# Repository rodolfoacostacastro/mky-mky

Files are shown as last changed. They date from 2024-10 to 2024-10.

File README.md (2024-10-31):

# A mky-mky clone for an RP2040 custom board

parasit

## Arduino Code

updated code after first workshop with minor improvements and better comments :)! 

This the code is situable for a makey makey that works with the chip RP2040.

To upload with the Arduino IDE, you will need to use this board definition(!):

https://github.com/earlephilhower/arduino-pico/releases/download/global/package_rp2040_index.json

go here --> Arduino >settings and scroll down until "Additional boards manager URLs" and paste the link above.

When selecting your board, asure you that it is the Raspberryi Pico/RP definition (and not the native from Arduino)

The code's been modified and works with the educational breakout-board created by Rodolfo Acosta Castro 
for the workshop "Into the Circuit" @ HfS, Berlin. October 2024

Credits:

 //////// MaKey MaKey FIRMWARE v1.4 /////////////
 by: Eric Rosenbaum, Jay Silver, and Jim Lindblom
 MIT Media Lab & Sparkfun
 release: 7/5/2012

## KiCad Files 

you find in this repository the KiCad Project files of the RP2040 Board and the Keyboard extension.
They were created using KiCad 8.0

## Fabrication Files

if you want to order the pcbs yourself you find all the needed files here

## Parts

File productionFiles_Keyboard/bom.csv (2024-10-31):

Designator | Footprint | Quantity | Value | LCSC Part #
Conn1 | mky_mky_boardPads | 1 | ~
GDN_pads1 | mky_mky_complete_GND | 1 | Conn_01x11_Pin
R1, R2, R3, R4, R5, R6, R7 | 0402 | 7 | 10M
TH_externPads1 | mky_mky_externPads | 1 | Conn_01x07_Pin

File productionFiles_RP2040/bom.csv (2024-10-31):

Designator | Footprint | Quantity | Value | LCSC Part #
C1, C2 | 0603 | 2 | 10pf | C1634
C10, C11, C12, C3, C4, C7, C9 | 0603 | 7 | 0.1uF | C14663
C13, C14 | 0805 | 2 | 10uf | C15850
C5, C6, C8 | 0603 | 3 | 1uF | C15849
Conn1 | rp2040_roundStamp_BIG | 1 | customConn
D1 | 0603 | 1 | LED | C189306
D3, D4 | D_SOD-323_HandSoldering | 2 | NSR0320 | C48192
F1 | 0805 | 1 | 500mA, 6V | C269104
J1 | USB_C_Receptacle_TYPE-C-31-M-12 | 1 | USB_C_Receptacle_USB2.0_16P | C165948
LED1 | LED-SMD_4P-L5.0-W5.0-TL_WS2812B-B | 1 | WS2812B-B/W | C2761795
R1, R8 | 0603 | 2 | 10k | C25804
R2, R7, R9 | 0603 | 3 | 1k | C21190
R3, R4 | 0603 | 2 | 5.1K | C23186
R5, R6 | 0603 | 2 | 27 | C100925
SW1, SW2 | SW_B3U-1000P | 2 | SW_Push | C231329
TP1, TP2 | TestPoint_Pad_D2.0mm | 2 | TestPoint
U1 | RP2040-QFN-56 | 1 | RP2040 | C2040
U2 | SON80P400X400X60-9N | 1 | W25Q64JVXGIQ 8MB QSPI Flash | C2940195
U3 | SOT-23-5 | 1 | AP2112K-3.3 | C23380830
X1 | CRYSTAL-SMD_4P-L3.2-W2.5-BL | 1 | ABM8-272-T3_C20625731 | C20625731

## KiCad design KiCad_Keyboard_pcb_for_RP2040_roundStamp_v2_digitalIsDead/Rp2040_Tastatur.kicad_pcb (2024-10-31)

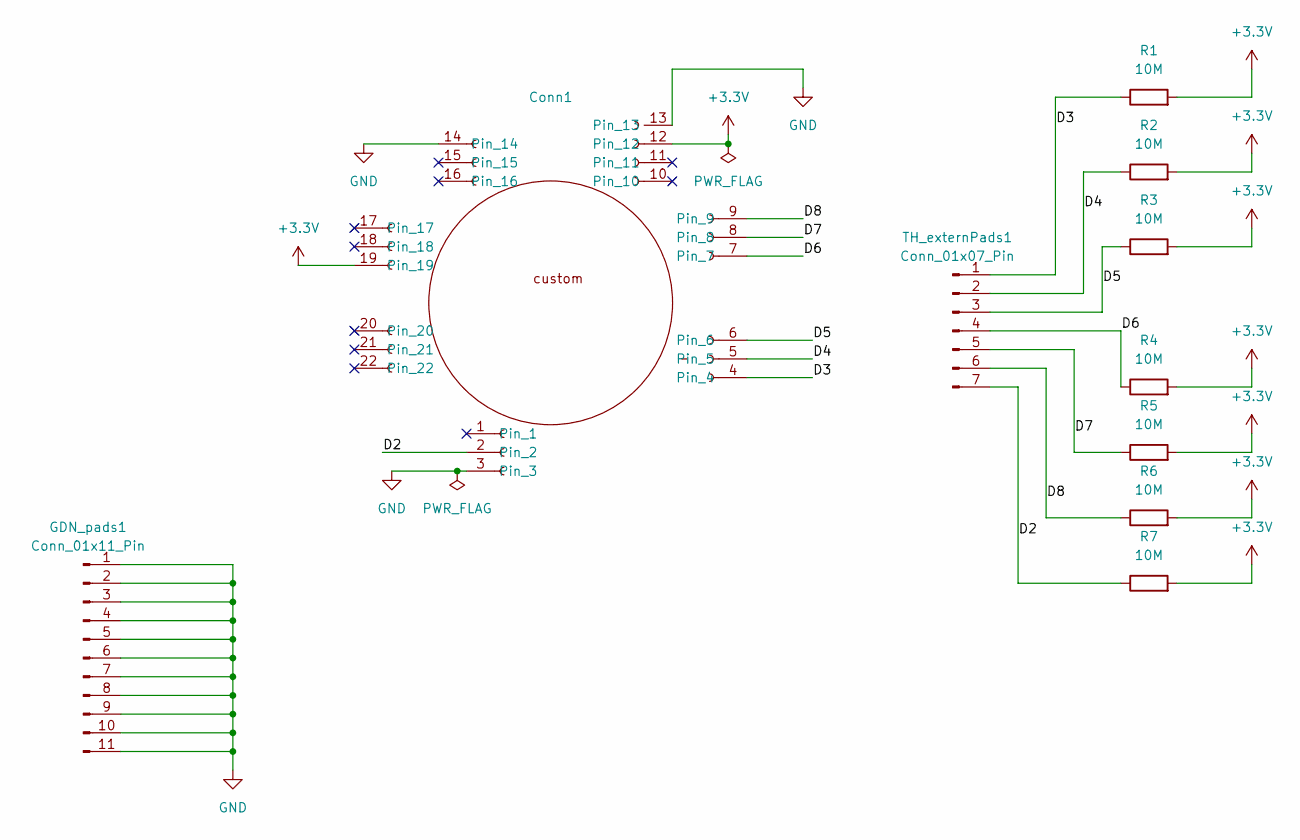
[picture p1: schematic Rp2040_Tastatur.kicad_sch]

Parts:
Conn1: mky_mky_boardPads
GDN_pads1: Conn_01x11_Pin; mky_mky_complete_GND
R1, R2, R3, R4, R5, R6, R7: 10M; R_0402_1005Metric_Pad0.72x0.64mm_HandSolder
TH_externPads1: Conn_01x07_Pin; mky_mky_externPads

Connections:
+3.3V: Conn1.12, Conn1.19, R1.2, R2.2, R3.2, R4.2, R5.2, R6.2, R7.2
/D2: Conn1.2, R7.1, TH_externPads1.7
/D3: Conn1.4, R1.1, TH_externPads1.1
/D4: Conn1.5, R2.1, TH_externPads1.2
/D5: Conn1.6, R3.1, TH_externPads1.3
/D6: Conn1.7, R4.1, TH_externPads1.4
/D7: Conn1.8, R5.1, TH_externPads1.5
/D8: Conn1.9, R6.1, TH_externPads1.6
GND: Conn1.3, Conn1.13, Conn1.14, GDN_pads1.1, GDN_pads1.2, GDN_pads1.3, GDN_pads1.4, GDN_pads1.5, GDN_pads1.6, GDN_pads1.7, GDN_pads1.8, GDN_pads1.9, GDN_pads1.10, GDN_pads1.11

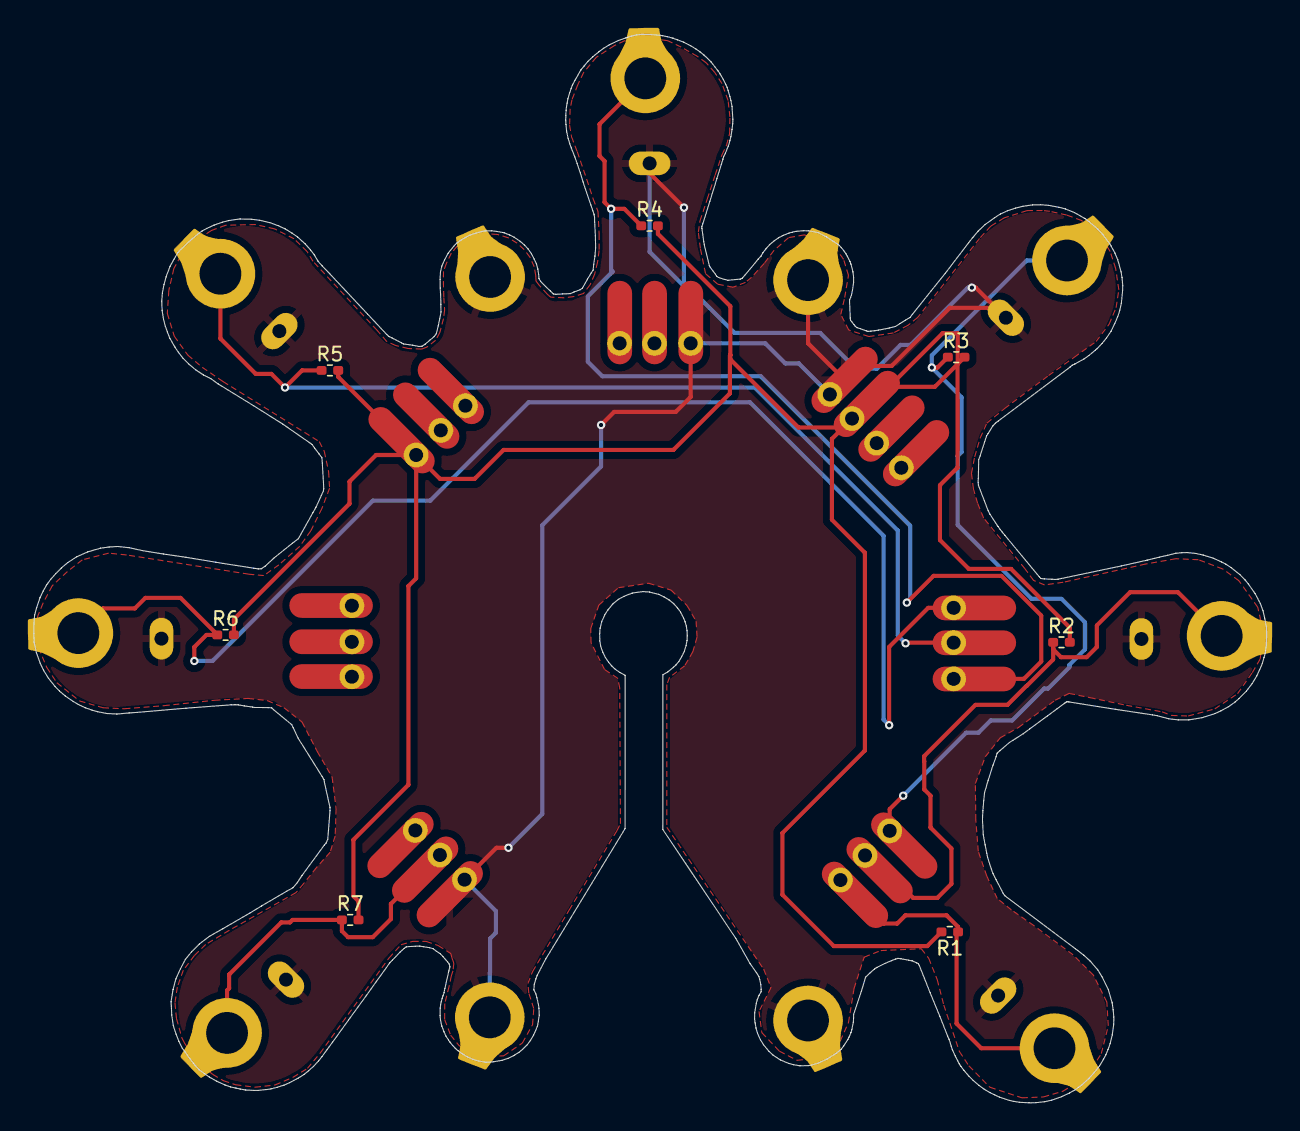
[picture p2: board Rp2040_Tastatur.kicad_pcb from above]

Board: 2 copper layers, 88.5 x 76.7 mm, 10 parts (0 on the bottom side), 9 nets.

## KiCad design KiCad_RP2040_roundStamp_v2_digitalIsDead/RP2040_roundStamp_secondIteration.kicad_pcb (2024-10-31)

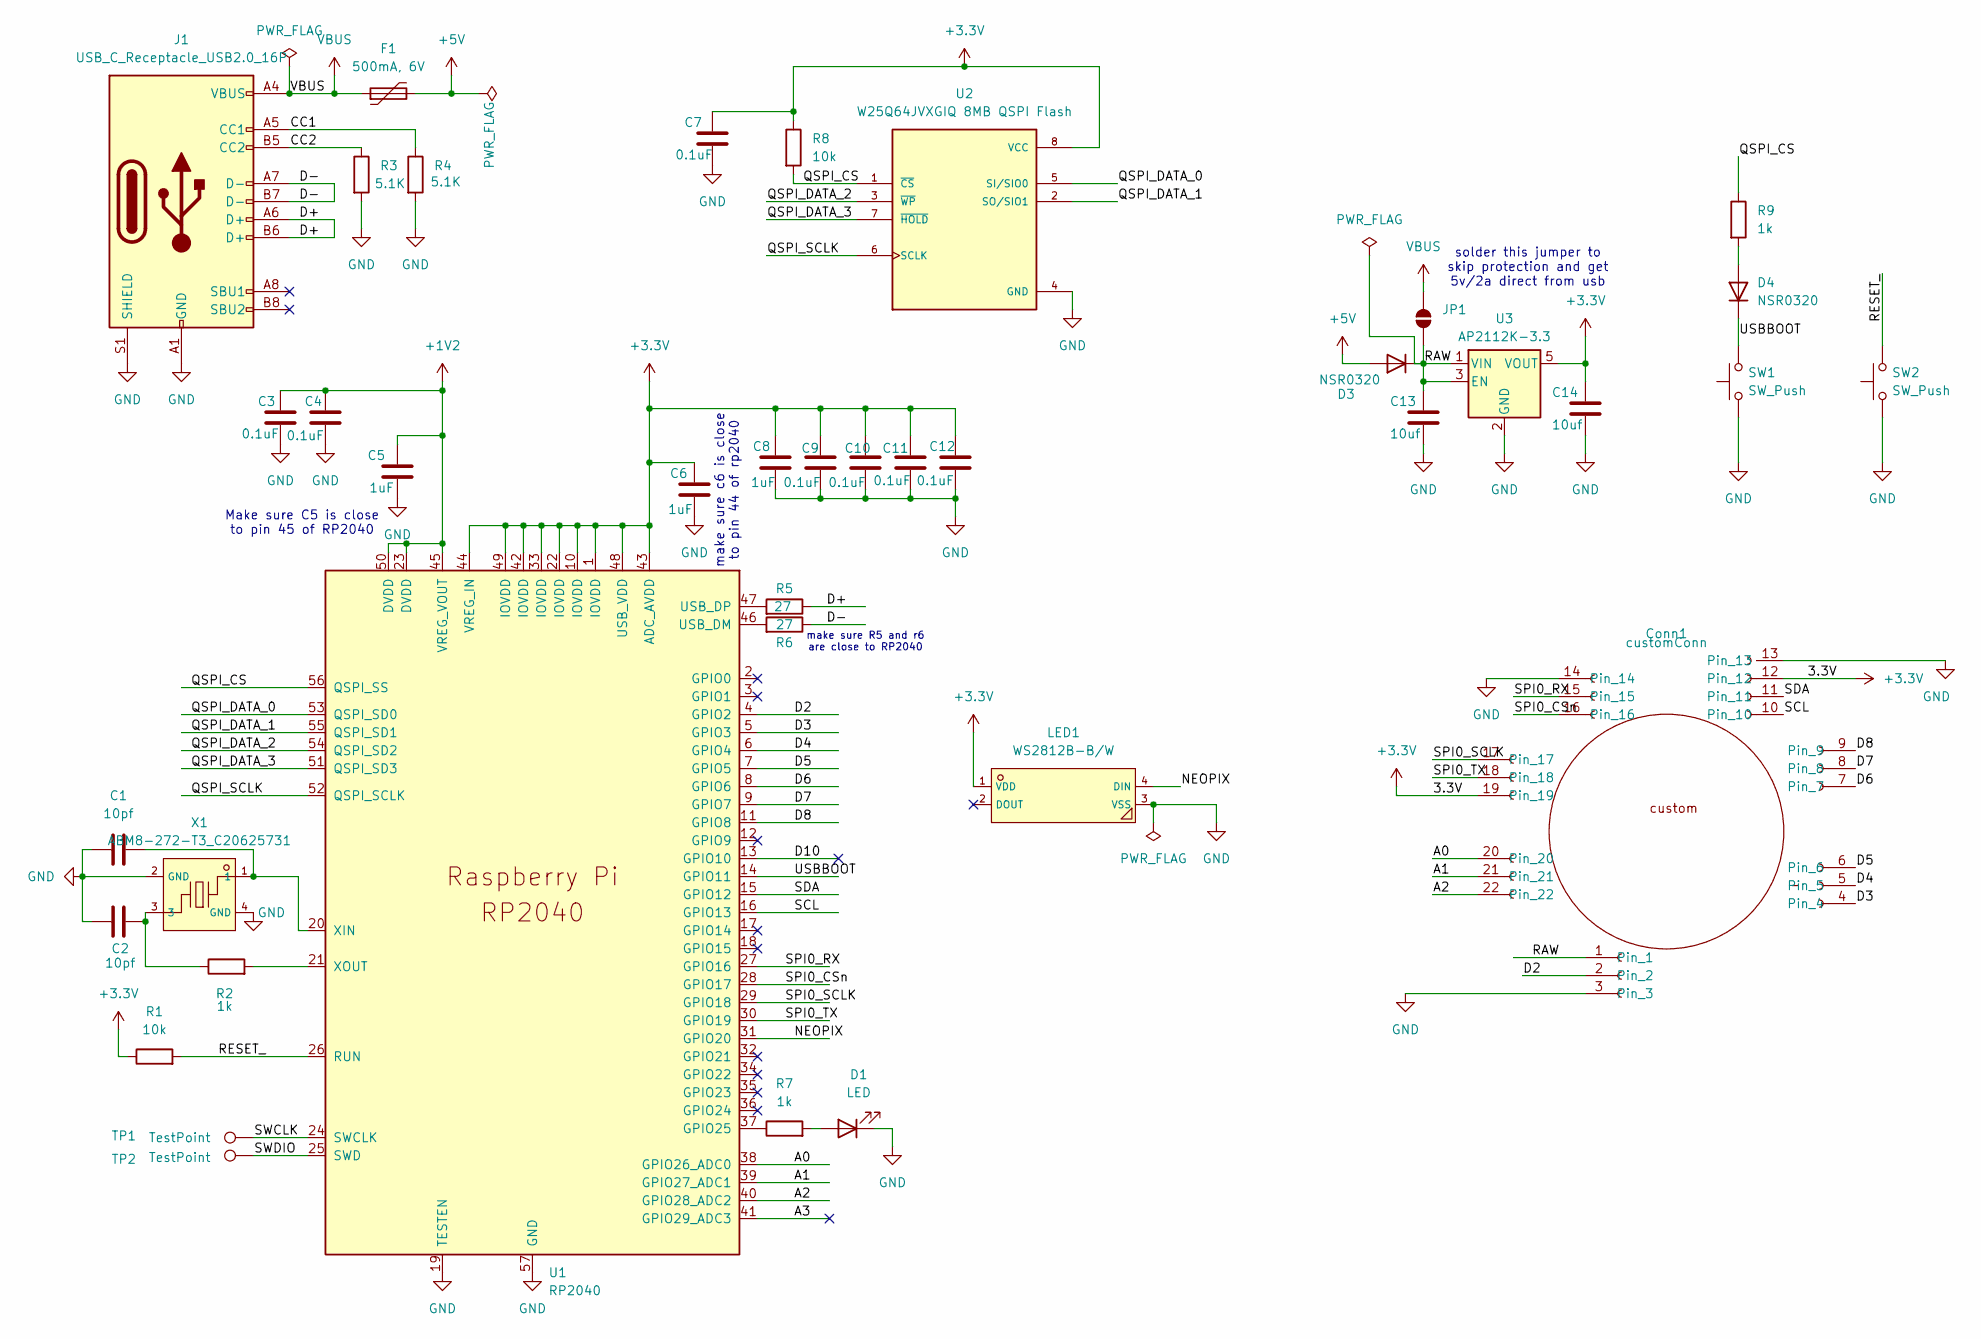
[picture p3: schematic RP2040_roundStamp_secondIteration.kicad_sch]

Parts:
C1, C2: 10pf; C_0603_1608Metric_Pad1.08x0.95mm_HandSolder; LCSC Part C1634
C3, C4, C7, C9, C10, C11, C12: 0.1uF; C_0603_1608Metric_Pad1.08x0.95mm_HandSolder; LCSC Part C14663
C5, C6, C8: 1uF; C_0603_1608Metric_Pad1.08x0.95mm_HandSolder; LCSC Part C15849
C13, C14: 10uf; C_0805_2012Metric_Pad1.18x1.45mm_HandSolder; LCSC Part C15850
Conn1: customConn; rp2040_roundStamp_BIG
D1: LED; LED_0603_1608Metric; LCSC Part C189306
D3, D4: NSR0320; D_SOD-323_HandSoldering; LCSC Part C48192
F1: 500mA, 6V; Fuse_0805_2012Metric; LCSC Part C269104
J1: USB_C_Receptacle_USB2.0_16P; USB_C_Receptacle_TYPE-C-31-M-12; LCSC Part C165948
JP1: SolderJumper_2_Open; SolderJumper-2_P1.3mm_Open_TrianglePad1.0x1.5mm
LED1: WS2812B-B/W; LED-SMD_4P-L5.0-W5.0-TL_WS2812B-B; LCSC C2761795
R1, R8: 10k; R_0603_1608Metric_Pad0.98x0.95mm_HandSolder; LCSC Part C25804
R2, R7, R9: 1k; R_0603_1608Metric_Pad0.98x0.95mm_HandSolder; LCSC Part C21190
R3, R4: 5.1K; R_0603_1608Metric_Pad0.98x0.95mm_HandSolder; LCSC Part C23186
R5, R6: 27; R_0603_1608Metric_Pad0.98x0.95mm_HandSolder; LCSC Part C100925
SW1, SW2: SW_Push; SW_B3U-1000P; LCSC Part C231329
TP1, TP2: TestPoint; TestPoint_Pad_D2.0mm
U1: RP2040; RP2040-QFN-56; LCSC Part C2040
U2: W25Q64JVXGIQ 8MB QSPI Flash; SON80P400X400X60-9N; LCSC Part C2940195
U3: AP2112K-3.3; SOT-23-5; LCSC Part C23380830
X1: ABM8-272-T3_C20625731; CRYSTAL-SMD_4P-L3.2-W2.5-BL; LCSC C20625731

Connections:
+1V2: C3.1, C4.1, C5.1, U1.23 (DVDD), U1.45 (VREG_VOUT), U1.50 (DVDD)
+3.3V: C6.1, C7.1, C8.1, C9.1, C10.1, C11.1, C12.1, C14.1, Conn1.12, Conn1.19, LED1.1 (VDD), R1.1, R8.1, U1.1 (IOVDD), U1.10 (IOVDD), U1.22 (IOVDD), U1.33 (IOVDD), U1.42 (IOVDD), U1.43 (ADC_AVDD), U1.44 (VREG_IN), U1.48 (USB_VDD), U1.49 (IOVDD), U2.8 (VCC), U3.5 (VOUT)
+5V: D3.2 (A), F1.2
/A0: Conn1.20, U1.38 (GPIO26_ADC0)
/A1: Conn1.21, U1.39 (GPIO27_ADC1)
/A2: Conn1.22, U1.40 (GPIO28_ADC2)
/A3: U1.41 (GPIO29_ADC3)
/CC1: J1.A5 (CC1), R4.1
/CC2: J1.B5 (CC2), R3.1
/D2: Conn1.2, U1.4 (GPIO2)
/D3: Conn1.4, U1.5 (GPIO3)
/D4: Conn1.5, U1.6 (GPIO4)
/D5: Conn1.6, U1.7 (GPIO5)
/D6: Conn1.7, U1.8 (GPIO6)
/D7: Conn1.8, U1.9 (GPIO7)
/D8: Conn1.9, U1.11 (GPIO8)
/D10: U1.13 (GPIO10)
/D+: J1.A6 (D+), J1.B6 (D+), R5.1
/D-: J1.A7 (D-), J1.B7 (D-), R6.1
/NEOPIX: LED1.4 (DIN), U1.31 (GPIO20)
/QSPI_CS: R8.2, R9.1, U1.56 (QSPI_SS), U2.1 (~CS)
/QSPI_DATA_0: U1.53 (QSPI_SD0), U2.5 (SI/SIO0)
/QSPI_DATA_1: U1.55 (QSPI_SD1), U2.2 (SO/SIO1)
/QSPI_DATA_2: U1.54 (QSPI_SD2), U2.3 (~WP)
/QSPI_DATA_3: U1.51 (QSPI_SD3), U2.7 (~HOLD)
/QSPI_SCLK: U1.52 (QSPI_SCLK), U2.6 (SCLK)
/RAW: C13.1, Conn1.1, D3.1 (K), JP1.1 (A), U3.1 (VIN), U3.3 (EN)
/RESET_: R1.2, SW2.2, U1.26 (RUN)
/SCL: Conn1.10, U1.16 (GPIO13)
/SDA: Conn1.11, U1.15 (GPIO12)
/SPI0_CSn: Conn1.16, U1.28 (GPIO17)
/SPI0_RX: Conn1.15, U1.27 (GPIO16)
/SPI0_SCLK: Conn1.17, U1.29 (GPIO18)
/SPI0_TX: Conn1.18, U1.30 (GPIO19)
/SWCLK: TP1.1, U1.24 (SWCLK)
/SWDIO: TP2.1, U1.25 (SWD)
/USBBOOT: D4.1 (K), SW1.2, U1.14 (GPIO11)
GND: C1.1, C2.1, C3.2, C4.2, C5.2, C6.2, C7.2, C8.2, C9.2, C10.2, C11.2, C12.2, C13.2, C14.2, Conn1.3, Conn1.13, Conn1.14, D1.1 (K), J1.A1 (GND), J1.A12 (GND), J1.B1 (GND), J1.B12 (GND), J1.S1 (SHIELD), LED1.3 (VSS), R3.2, R4.2, SW1.1, SW2.1, U1.19 (TESTEN), U1.57 (GND), U2.4 (GND), U3.2 (GND), X1.2 (GND), X1.4 (GND)
unnamed: C2.2, R2.1, X1.3
unnamed: D1.2 (A), R7.2
unnamed: D4.2 (A), R9.2
unnamed: R7.1, U1.37 (GPIO25)
unnamed: R6.2, U1.46 (USB_DM)
unnamed: R5.2, U1.47 (USB_DP)
unnamed: C1.2, U1.20 (XIN), X1.1
unnamed: R2.2, U1.21 (XOUT)
VBUS: F1.1, J1.A4 (VBUS), J1.A9 (VBUS), J1.B4 (VBUS), J1.B9 (VBUS), JP1.2

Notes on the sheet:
make sure R5 and r6 are close to RP2040
make sure c6 is close to pin 44 of rp2040
Make sure C5 is close to pin 45 of RP2040
solder this jumper to skip protection and get 5v/2a direct from usb

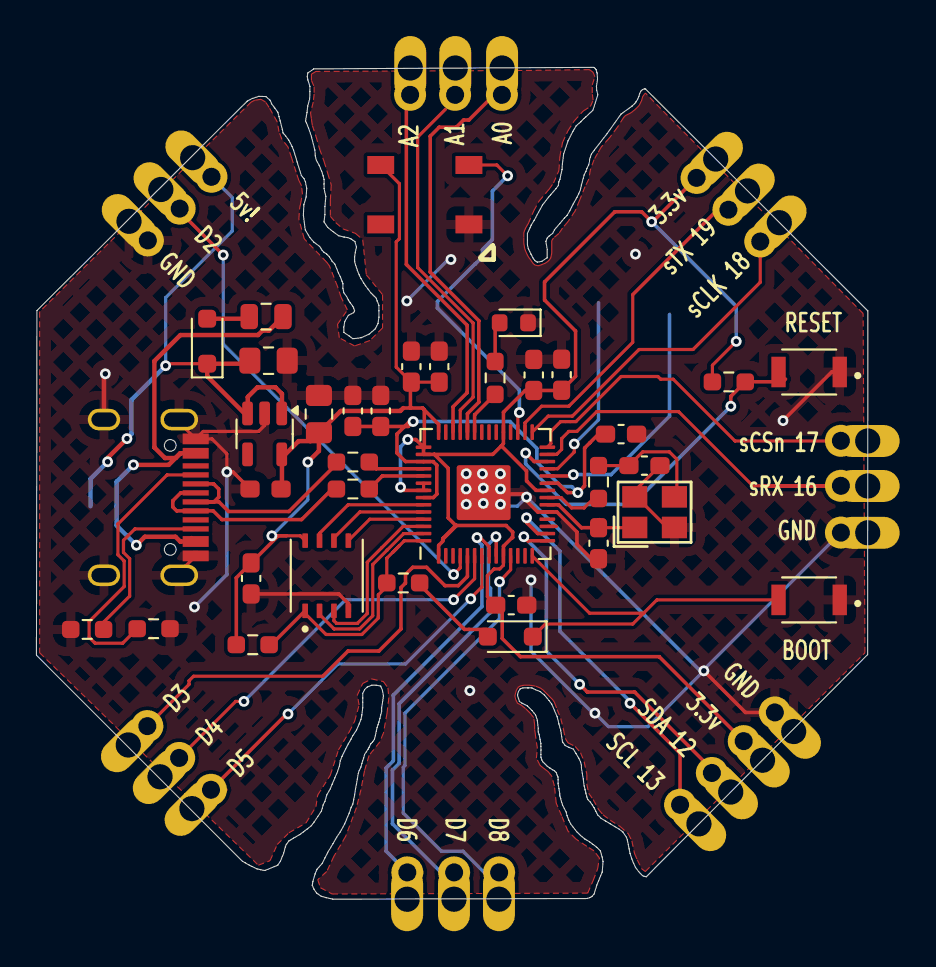
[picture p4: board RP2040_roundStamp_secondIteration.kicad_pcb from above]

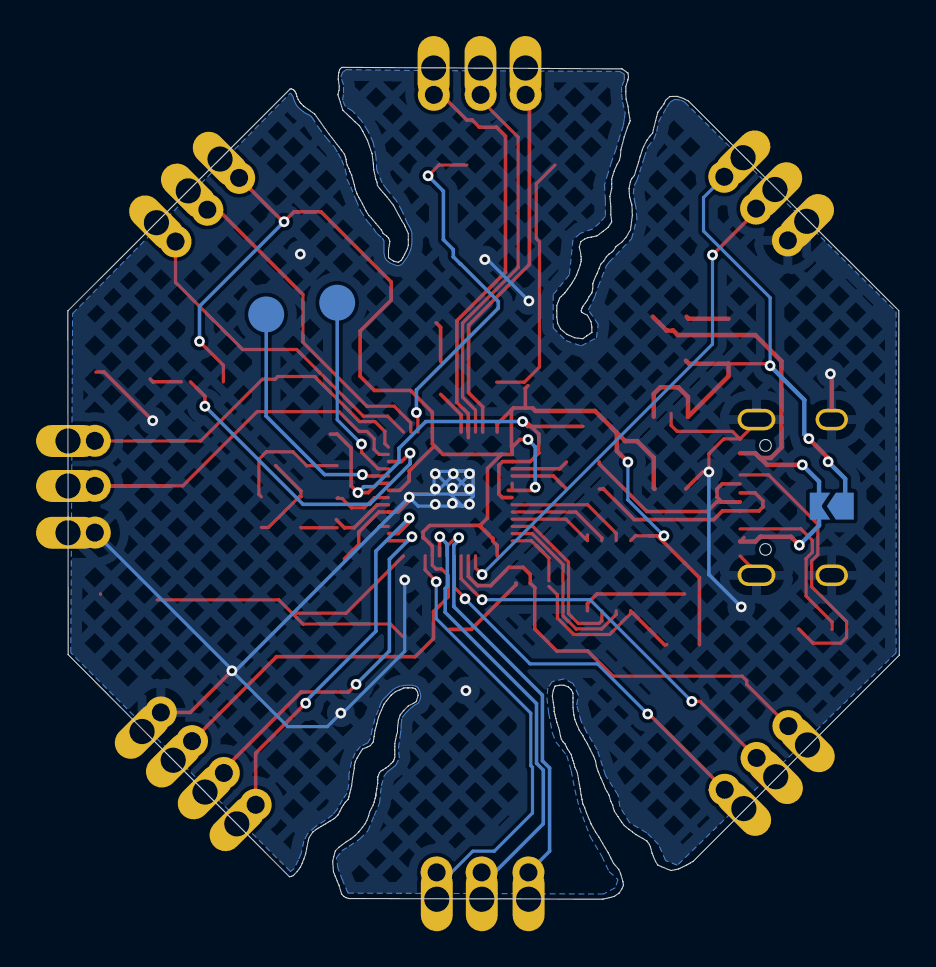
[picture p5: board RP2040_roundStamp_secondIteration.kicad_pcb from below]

Board: 2 copper layers, 46.2 x 46.2 mm, 39 parts (3 on the bottom side), 45 nets.

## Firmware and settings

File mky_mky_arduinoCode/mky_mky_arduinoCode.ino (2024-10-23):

/*

This is the code for the makey makey clone, that works with the chip RP2040.
You need to use this core to use it as a keyboard:
https://github.com/earlephilhower/arduino-pico/releases/download/global/package_rp2040_index.json

The code's been modified and works with the educational breakout-board created by Rodolfo Acosta Castro 
for the workshop "Into the Circuit" @ HfS, Berlin. October 2024

Credits:
 ************** MAKEY MAKEY *********************
 /////////////HOW TO EDIT THE KEYS //////// /////////////////////////////////////////////////
///////
 - Edit keys in the settings.h file
 - that file should be open in a tab above (in Arduino IDE)
 - more instructions are in that file
 
 //////// MaKey MaKey FIRMWARE v1.4 /////////////
 by: Eric Rosenbaum, Jay Silver, and Jim Lindblom
 MIT Media Lab & Sparkfun
 release: 7/5/2012
 */

////////////////////////
// DEFINED CONSTANTS////
////////////////////////

#define BUFFER_LENGTH    3     // 3 bytes gives us 24 samples
#define NUM_INPUTS       7   // 6 on the front + 12 on the back
//#define TARGET_LOOP_TIME 694   // (1/60 seconds) / 24 samples = 694 microseconds per sample 
//#define TARGET_LOOP_TIME 758  // (1/55 seconds) / 24 samples = 758 microseconds per sample 
#define TARGET_LOOP_TIME 744  // (1/56 seconds) / 24 samples = 744 microseconds per sample 

// id numbers for mouse movement inputs (used in settings.h)
#define MOUSE_MOVE_UP       -1 
#define MOUSE_MOVE_DOWN     -2
#define MOUSE_MOVE_LEFT     -3
#define MOUSE_MOVE_RIGHT    -4

#include <Keyboard.h>
#include <Mouse.h>
#include "settings.h"

/////////////////////////
// STRUCT ///////////////
/////////////////////////
typedef struct {
  byte pinNumber;
  int keyCode;
  byte measurementBuffer[BUFFER_LENGTH]; 
  boolean oldestMeasurement;
  byte bufferSum;
  boolean pressed;
  boolean prevPressed;
  boolean isMouseMotion;
  boolean isMouseButton;
  boolean isKey;
} 
MakeyMakeyInput;

MakeyMakeyInput inputs[NUM_INPUTS];

///////////////////////////////////
// VARIABLES //////////////////////
///////////////////////////////////
int bufferIndex = 0;
byte byteCounter = 0;
byte bitCounter = 0;
int mouseMovementCounter = 0; // for sending mouse movement events at a slower interval

int pressThreshold;
int releaseThreshold;
boolean inputChanged;

int mouseHoldCount[NUM_INPUTS]; // used to store mouse movement hold data

// Pin Numbers
int pinNumbers[NUM_INPUTS] = {
 2, 3, 4, 5, 6, 7, 8  // top of board
};

// input status LED pin numbers
const int inputLED_a = 25;
byte ledCycleCounter = 0;

 // timing
int loopTime = 0;
int prevTime = 0;
int loopCounter = 0;       

///////////////////////////
// FUNCTIONS //////////////
///////////////////////////
void initializeArduino();
void initializeInputs();
void updateMeasurementBuffers();
void updateBufferSums();
void updateBufferIndex();
void updateInputStates();
void sendMouseButtonEvents();
void sendMouseMovementEvents();
void addDelay();
void cycleLEDs();
//void danceLeds();

//////////////////////
// SETUP /////////////
//////////////////////
void setup() 
{
  initializeArduino();
  initializeInputs();
  danceLeds();
}

////////////////////
// MAIN LOOP ///////
////////////////////
void loop() 
{
  updateMeasurementBuffers();
  updateBufferSums();
  updateBufferIndex();
  updateInputStates();
  sendMouseButtonEvents();
  sendMouseMovementEvents();
  cycleLEDs();
  addDelay();
}

//////////////////////////
// INITIALIZE ARDUINO
//////////////////////////
void initializeArduino() {
#ifdef DEBUG
  Serial.begin(9600);  // Serial for debugging
#endif

  /* Set up input pins 
   DEactivate the internal pull-ups, since we're using external resistors */
  for (int i=0; i<NUM_INPUTS; i++)
  {
    pinMode(pinNumbers[i], INPUT);
    digitalWrite(pinNumbers[i], LOW);
  }

  pinMode(inputLED_a, OUTPUT);
  digitalWrite(inputLED_a, LOW);

#ifdef DEBUG
  delay(4000); // allow us time to reprogram in case things are freaking out
#endif

  Keyboard.begin();
  Mouse.begin();
}

///////////////////////////
// INITIALIZE INPUTS
///////////////////////////
void initializeInputs() {

  float thresholdPerc = SWITCH_THRESHOLD_OFFSET_PERC;
  float thresholdCenterBias = SWITCH_THRESHOLD_CENTER_BIAS/50.0;
  float pressThresholdAmount = (BUFFER_LENGTH * 8) * (thresholdPerc / 100.0);
  float thresholdCenter = ( (BUFFER_LENGTH * 8) / 2.0 ) * (thresholdCenterBias);
  pressThreshold = int(thresholdCenter + pressThresholdAmount);
  releaseThreshold = int(thresholdCenter - pressThresholdAmount);

#ifdef DEBUG
  Serial.println(pressThreshold);
  Serial.println(releaseThreshold);
#endif

  for (int i=0; i<NUM_INPUTS; i++) {
    inputs[i].pinNumber = pinNumbers[i];
    inputs[i].keyCode = keyCodes[i];

    for (int j=0; j<BUFFER_LENGTH; j++) {
      inputs[i].measurementBuffer[j] = 0;
    }
    inputs[i].oldestMeasurement = 0;
    inputs[i].bufferSum = 0;

    inputs[i].pressed = false;
    inputs[i].prevPressed = false;

    inputs[i].isMouseMotion = false;
    inputs[i].isMouseButton = false;
    inputs[i].isKey = false;

    if (inputs[i].keyCode < 0) {
#ifdef DEBUG_MOUSE
      Serial.println("GOT IT");  
#endif

      inputs[i].isMouseMotion = true;
    } 
    else if ((inputs[i].keyCode == MOUSE_LEFT) || (inputs[i].keyCode == MOUSE_RIGHT)) {
      inputs[i].isMouseButton = true;
    } 
    else {
      inputs[i].isKey = true;
    }
#ifdef DEBUG
    Serial.println(i);
#endif

  }
}


//////////////////////////////
// UPDATE MEASUREMENT BUFFERS
//////////////////////////////
void updateMeasurementBuffers() {

  for (int i=0; i<NUM_INPUTS; i++) {

    // store the oldest measurement, which is the one at the current index,
    // before we update it to the new one 
    // we use oldest measurement in updateBufferSums
    byte currentByte = inputs[i].measurementBuffer[byteCounter];
    inputs[i].oldestMeasurement = (currentByte >> bitCounter) & 0x01; 

    // make the new measurement
    boolean newMeasurement = digitalRead(inputs[i].pinNumber);

    // invert so that true means the switch is closed
    newMeasurement = !newMeasurement; 

    // store it    
    if (newMeasurement) {
      currentByte |= (1<<bitCounter);
    } 
    else {
      currentByte &= ~(1<<bitCounter);
    }
    inputs[i].measurementBuffer[byteCounter] = currentByte;
  }
}

///////////////////////////
// UPDATE BUFFER SUMS
///////////////////////////
void updateBufferSums() {

  // the bufferSum is a running tally of the entire measurementBuffer
  // add the new measurement and subtract the old one

  for (int i=0; i<NUM_INPUTS; i++) {
    byte currentByte = inputs[i].measurementBuffer[byteCounter];
    boolean currentMeasurement = (currentByte >> bitCounter) & 0x01; 
    if (currentMeasurement) {
      inputs[i].bufferSum++;
    }
    if (inputs[i].oldestMeasurement) {
      inputs[i].bufferSum--;
    }
  }  
}

///////////////////////////
// UPDATE BUFFER INDEX
///////////////////////////
void updateBufferIndex() {
  bitCounter++;
  if (bitCounter == 8) {
    bitCounter = 0;
    byteCounter++;
    if (byteCounter == BUFFER_LENGTH) {
      byteCounter = 0;
    }
  }
}

///////////////////////////
// UPDATE INPUT STATES
///////////////////////////
void updateInputStates() {
  inputChanged = false;
  for (int i=0; i<NUM_INPUTS; i++) {
    inputs[i].prevPressed = inputs[i].pressed; // store previous pressed state (only used for mouse buttons)
    if (inputs[i].pressed) {
      if (inputs[i].bufferSum < releaseThreshold) {  
        inputChanged = true;
        inputs[i].pressed = false;
        if (inputs[i].isKey) {
          Keyboard.release(inputs[i].keyCode);
        }
        if (inputs[i].isMouseMotion) {  
          mouseHoldCount[i] = 0;  // input becomes released, reset mouse hold
        }
      }
      else if (inputs[i].isMouseMotion) {  
        mouseHoldCount[i]++; // input remains pressed, increment mouse hold
      }
    } 
    else if (!inputs[i].pressed) {
      if (inputs[i].bufferSum > pressThreshold) {  // input becomes pressed
        inputChanged = true;
        inputs[i].pressed = true; 
        if (inputs[i].isKey) {
          Keyboard.press(inputs[i].keyCode);
        }
      }
    }
  }
#ifdef DEBUG3
  if (inputChanged) {
    Serial.println("change");
  }
#endif
}

/////////////////////////////
// SEND MOUSE BUTTON EVENTS 
/////////////////////////////
void sendMouseButtonEvents() {
  if (inputChanged) {
    for (int i=0; i<NUM_INPUTS; i++) {
      if (inputs[i].isMouseButton) {
        if (inputs[i].pressed) {
          if (inputs[i].keyCode == MOUSE_LEFT) {
            Mouse.press(MOUSE_LEFT);
          } 
          if (inputs[i].keyCode == MOUSE_RIGHT) {
            Mouse.press(MOUSE_RIGHT);
          } 
        } 
        else if (inputs[i].prevPressed) {
          if (inputs[i].keyCode == MOUSE_LEFT) {
            Mouse.release(MOUSE_LEFT);
          } 
          if (inputs[i].keyCode == MOUSE_RIGHT) {
            Mouse.release(MOUSE_RIGHT);
          }           
        }
      }
    }
  }
}

//////////////////////////////
// SEND MOUSE MOVEMENT EVENTS
//////////////////////////////
void sendMouseMovementEvents() {
  byte right = 0;
  byte left = 0;
  byte down = 0;
  byte up = 0;
  byte horizmotion = 0;
  byte vertmotion = 0;

  mouseMovementCounter++;
  mouseMovementCounter %= MOUSE_MOTION_UPDATE_INTERVAL;
  if (mouseMovementCounter == 0) {
    for (int i=0; i<NUM_INPUTS; i++) {
#ifdef DEBUG_MOUSE
      //  Serial.println(inputs[i].isMouseMotion);  
#endif

      if (inputs[i].isMouseMotion) {
        if (inputs[i].pressed) {
          if (inputs[i].keyCode == MOUSE_MOVE_UP) {
            // JL Changes (x4): now update to 1 + a hold factor, constrained between 1 and mouse max movement speed
            up=constrain(1+mouseHoldCount[i]/MOUSE_RAMP_SCALE, 1, MOUSE_MAX_PIXELS);
          }  
          if (inputs[i].keyCode == MOUSE_MOVE_DOWN) {
            down=constrain(1+mouseHoldCount[i]/MOUSE_RAMP_SCALE, 1, MOUSE_MAX_PIXELS);
          }  
          if (inputs[i].keyCode == MOUSE_MOVE_LEFT) {
            left=constrain(1+mouseHoldCount[i]/MOUSE_RAMP_SCALE, 1, MOUSE_MAX_PIXELS);
          }  
          if (inputs[i].keyCode == MOUSE_MOVE_RIGHT) {
            right=constrain(1+mouseHoldCount[i]/MOUSE_RAMP_SCALE, 1, MOUSE_MAX_PIXELS);
          }  
        }
      }
    }

    // diagonal scrolling and left/right cancellation
    if(left > 0)
    {
      if(right > 0)
      {
        horizmotion = 0; // cancel horizontal motion because left and right are both pushed
      }
      else
      {
        horizmotion = -left; // left yes, right no
      }
    }
    else
    {
      if(right > 0)
      {
        horizmotion = right; // right yes, left no
      }
    }

    if(down > 0)
    {
      if(up > 0)
      {
        vertmotion = 0; // cancel vertical motion because up and down are both pushed
      }
      else
      {
        vertmotion = down; // down yes, up no
      }
    }
    else
    {
      if (up > 0)
      {
        vertmotion = -up; // up yes, down no
      }
    }
    // now move the mouse
    if( !((horizmotion == 0) && (vertmotion==0)) )
    {
      Mouse.move(horizmotion * PIXELS_PER_MOUSE_STEP, vertmotion * PIXELS_PER_MOUSE_STEP);
    }
  }
}

///////////////////////////
// ADD DELAY
///////////////////////////
void addDelay() {

  loopTime = micros() - prevTime;
  if (loopTime < TARGET_LOOP_TIME) {
    int wait = TARGET_LOOP_TIME - loopTime;
    delayMicroseconds(wait);
  }

  prevTime = micros();

#ifdef DEBUG_TIMING
  if (loopCounter == 0) {
    int t = micros()-prevTime;
    Serial.println(t);
  }
  loopCounter++;
  loopCounter %= 999;
#endif

}

///////////////////////////
// CYCLE LEDS
///////////////////////////

void cycleLEDs() {

  pinMode(inputLED_a, INPUT);
  digitalWrite(inputLED_a, LOW);

  ledCycleCounter++;
  ledCycleCounter %= 7;

  if ((ledCycleCounter == 0) && inputs[0].pressed) {
    pinMode(inputLED_a, OUTPUT);
    digitalWrite(inputLED_a, HIGH);
  }
  if ((ledCycleCounter == 1) && inputs[1].pressed) {
    pinMode(inputLED_a, OUTPUT);
    digitalWrite(inputLED_a, HIGH);
  }
  if ((ledCycleCounter == 2) && inputs[2].pressed) {
    pinMode(inputLED_a, OUTPUT);
    digitalWrite(inputLED_a, HIGH);
  }
  if ((ledCycleCounter == 3) && inputs[3].pressed) {
    pinMode(inputLED_a, OUTPUT);
    digitalWrite(inputLED_a, HIGH);
  }
  if ((ledCycleCounter == 4) && inputs[4].pressed) {
    pinMode(inputLED_a, OUTPUT);
    digitalWrite(inputLED_a, HIGH);
 
  }
  if ((ledCycleCounter == 5) && inputs[5].pressed) {
    pinMode(inputLED_a, OUTPUT);
    digitalWrite(inputLED_a, HIGH);
  }
    if ((ledCycleCounter == 5) && inputs[6].pressed) {
    pinMode(inputLED_a, OUTPUT);
    digitalWrite(inputLED_a, HIGH);
  }

}

///////////////////////////
// DANCE LEDS
///////////////////////////
void danceLeds()
{
      digitalWrite(inputLED_a, HIGH);
      delay (250);
      digitalWrite(inputLED_a, LOW);
      delay (250);
      digitalWrite(inputLED_a, HIGH);
      delay (250);
      digitalWrite(inputLED_a, LOW);
      delay (250);
      
      digitalWrite(inputLED_a, HIGH);
      delay (100);
      digitalWrite(inputLED_a, LOW);
      delay (100);
      digitalWrite(inputLED_a, HIGH);
      delay (100);
      digitalWrite(inputLED_a, LOW);
      delay (100);
      
      digitalWrite(inputLED_a, HIGH);
      delay (250);
      digitalWrite(inputLED_a, LOW);
      delay (250);
      digitalWrite(inputLED_a, HIGH);
      delay (250);
      digitalWrite(inputLED_a, LOW);

}

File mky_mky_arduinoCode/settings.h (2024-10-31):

#include "Arduino.h"

/*
/////////////////////////////////////////////////////////////////////////
// KEY MAPPINGS: WHICH KEY MAPS TO WHICH PIN ON THE MAKEY MAKEY BOARD? //
/////////////////////////////////////////////////////////////////////////
  
  - edit the keyCodes array below to change the keys sent by the MaKey MaKey for each input
  - the comments tell you which input sends that key 
  - change the keys by replacing them. for example, you can replace 'w' with any other individual letter,
    number, or symbol on your keyboard
  - you can also use codes for other keys such as modifier and function keys (see the
    the list of additional key codes at the bottom of this file)

*/

int keyCodes[NUM_INPUTS] = {
 
 // KEY_UP_ARROW,      // up arrow pad
 // KEY_DOWN_ARROW,    // down arrow pad
 // KEY_LEFT_ARROW,    // left arrow pad
  //KEY_RIGHT_ARROW,   // right arrow pad
  // ' ',              // space button pad
  //MOUSE_LEFT,        // click button pad


  's',                 //*first leg of the board (clock-wise)
  KEY_DOWN_ARROW,      //*last  leg of the board (clock-wise)
  'd',                 //*sixth  leg of the board (clock-wise) 
  'e',                 //*fifth  leg of the board (clock-wise)
  KEY_UP_ARROW,        //*forth leg of the board (the middle one!)
  'q',                 //*third leg of the board (clock-wise)
  'a'                  //*second leg of the board (clock-wise)
  
 // MOUSE_MOVE_UP,      
 // MOUSE_MOVE_DOWN,    
 // MOUSE_MOVE_LEFT,    
 // MOUSE_MOVE_RIGHT,   
 // MOUSE_LEFT,         
 // MOUSE_RIGHT         
};

///////////////////////////
// NOISE CANCELLATION /////
///////////////////////////
#define SWITCH_THRESHOLD_OFFSET_PERC  5    // number between 1 and 49
                                           // larger value protects better against noise oscillations, but makes it harder to press and release
                                           // recommended values are between 2 and 20
                                           // default value is 5

#define SWITCH_THRESHOLD_CENTER_BIAS 55   // number between 1 and 99
                                          // larger value makes it easier to "release" keys, but harder to "press"
                                          // smaller value makes it easier to "press" keys, but harder to "release"
                                          // recommended values are between 30 and 70
                                          // 50 is "middle" 2.5 volt center
                                          // default value is 55
                                          // 100 = 5V (never use this high)
                                          // 0 = 0 V (never use this low
                                          

/////////////////////////
// MOUSE MOTION /////////
/////////////////////////
#define MOUSE_MOTION_UPDATE_INTERVAL  35   // how many loops to wait between 
                                           // sending mouse motion updates
                                           
#define PIXELS_PER_MOUSE_STEP         4     // a larger number will make the mouse
                                           // move faster

#define MOUSE_RAMP_SCALE              150  // Scaling factor for mouse movement ramping
                                           // Lower = more sensitive mouse movement
                                           // Higher = slower ramping of speed
                                           // 0 = Ramping off
                                            
#define MOUSE_MAX_PIXELS              10   // Max pixels per step for mouse movement

/*

///////////////////////////
// ADDITIONAL KEY CODES ///
///////////////////////////

- you can use these codes in the keyCodes array above
- to get modifier keys, function keys, etc 

KEY_LEFT_CTRL
KEY_LEFT_SHIFT		
KEY_LEFT_ALT		
KEY_LEFT_GUI		
KEY_RIGHT_CTRL		
KEY_RIGHT_SHIFT		
KEY_RIGHT_ALT	
KEY_RIGHT_GUI		

KEY_BACKSPACE		
KEY_TAB				
KEY_RETURN			
KEY_ESC				
KEY_INSERT			
KEY_DELETE			
KEY_PAGE_UP			
KEY_PAGE_DOWN		
KEY_HOME
KEY_END				
KEY_CAPS_LOCK	
	
KEY_F1				
KEY_F2				
KEY_F3				
KEY_F4				
KEY_F5				
KEY_F6				
KEY_F7				
KEY_F8				
KEY_F9				
KEY_F10
KEY_F11				
KEY_F12			

*/	
                                           
                                           

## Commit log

2024-10-31 Delete RP2040_roundStamp_v2_digitalIsDead directory
    take out unnecessary folders
    [RP2040_roundStamp_secondIteration.kicad_pcb, RP2040_roundStamp_secondIteration.kicad_sch]
2024-10-31 Update README.md
    details about kicad
2024-10-31 Delete Keyboard_pcb_for_RP2040_roundStamp_v2 directory
    borrando por tener nombre confuso 1
    [Rp2040_Tastatur.kicad_pcb, Rp2040_Tastatur.kicad_sch]
2024-10-31 Delete RP2040_roundStamp_v2_digitalIsDead directory
    borrando por tener nombre confuso 2
    [RP2040_roundStamp_secondIteration.kicad_pcb, RP2040_roundStamp_secondIteration.kicad_sch]
